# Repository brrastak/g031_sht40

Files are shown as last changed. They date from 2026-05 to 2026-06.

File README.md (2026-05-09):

# Temperature and humidity measuring device

Consists of:

- [SHT40 Temperature & Humidity Sensor](https://www.adafruit.com/product/4885);
- [1.02inch E-Ink display module](https://www.waveshare.com/1.02inch-e-paper-module.htm);
- [AEM10491 solar energy harvesting module](https://www.tindie.com/products/jaspersikken/solar-harvesting-into-supercapacitors/);
- two supercaps to store the energy;

all controlled by a rust-powered STM32G031 micro!

## Images

### Breadboard edition

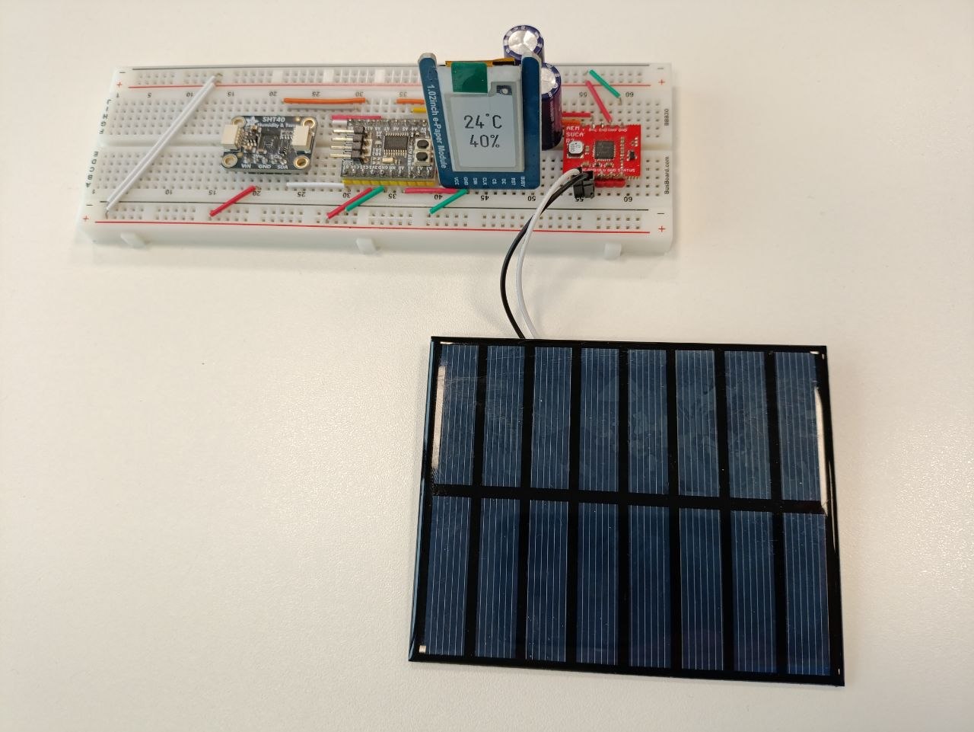
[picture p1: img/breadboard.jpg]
Breadboard


## Solar harvester

### Voltage thresholds

Enable threshold: 3.92V

Disable threshold: 3.60V

Unfortunately, the system doesn't work when supplied by 2.5V.

[AEM10491 datasheet](https://www.mouser.sk/datasheet/3/3770/1/DS_AEM10941.pdf)

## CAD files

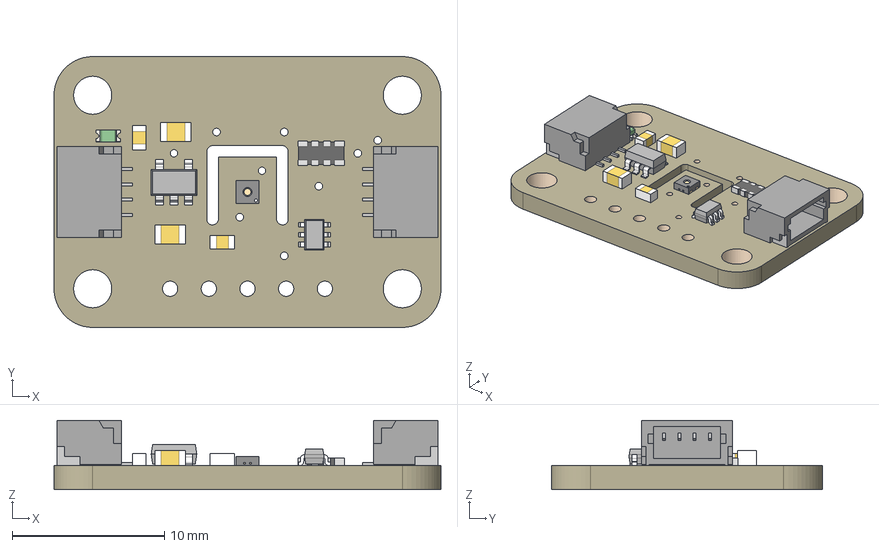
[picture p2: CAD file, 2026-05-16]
hardware/3d-models/SHT40.step
25.4 x 17.8 x 4.53 mm
Board
10uF x 2
AP2112K-3.3
10K x 2
10K_1
BSS138
STEMMA_I2C_QT x 2
GREEN
SHT4X_

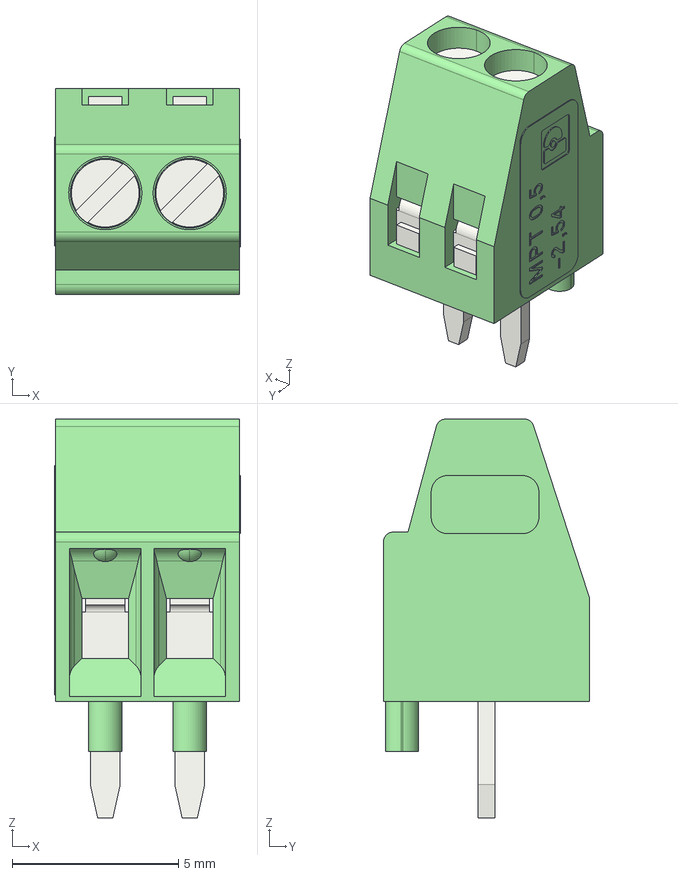
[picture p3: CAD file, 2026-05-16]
hardware/3d-models/1725656.stp
5.60 x 6.20 x 12.0 mm

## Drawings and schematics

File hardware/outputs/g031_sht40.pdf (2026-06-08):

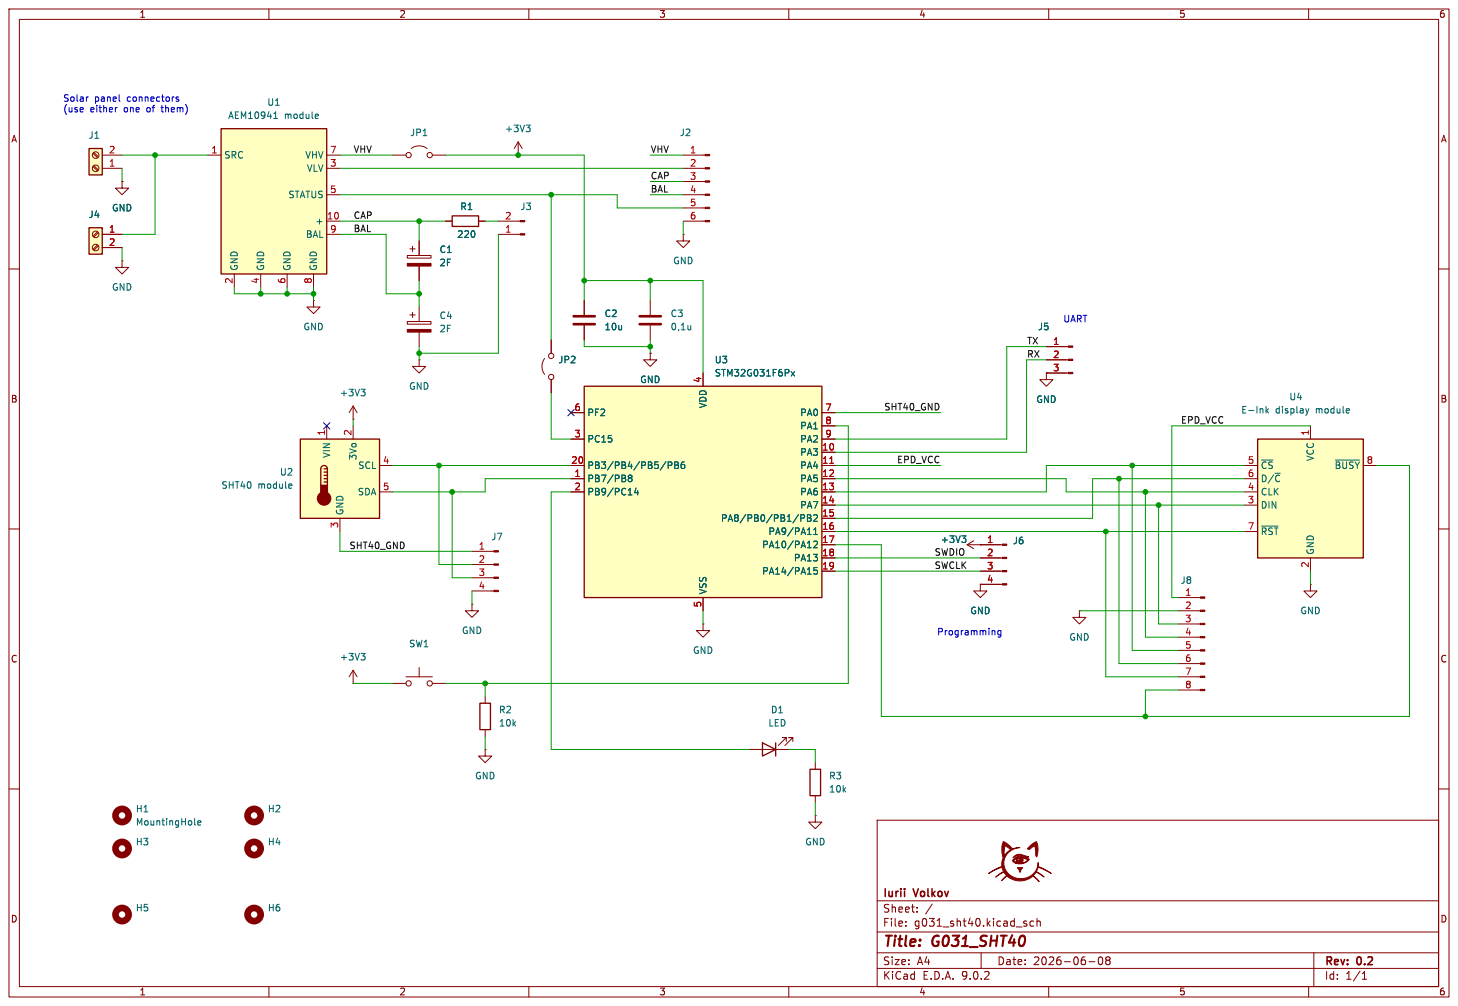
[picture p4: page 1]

(use either one of them) GND J4
10u GND GND

2 ~{BUSY}8 U4 E-Ink display module

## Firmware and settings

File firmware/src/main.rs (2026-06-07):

#![deny(unsafe_code)]
#![no_main]
#![no_std]

use defmt;
// Global logger
use defmt_rtt as _;
use hal::rtc::{self, Rtc};
use panic_halt as _;
use stm32g0xx_hal as hal;

use g031_sht40::bsp::{Board, Display, Led, Sensor};
use g031_sht40::data::{Data, UpdateStatus};

#[rtic::app(device = hal::pac, peripherals = true, dispatchers = [EXTI4_15])]
mod app {

    use super::*;

    #[shared]
    struct Shared {}

    #[local]
    struct Local {
        display: Display,
        sensor: Sensor,
        prev_data: Option<Data>,
        rtc: Rtc,
        led: Led,
    }

    #[init]
    fn init(cx: init::Context) -> (Shared, Local) {
        let board = Board::new(cx.device, cx.core);
        defmt::info!("Initialization finished!");

        let display = board.display;
        let sensor = board.sensor;
        let rtc = board.rtc;
        let led = board.led;

        let prev_data: Option<Data> = None;

        system_task::spawn().ok();

        (
            Shared {},
            Local {
                display,
                sensor,
                prev_data,
                rtc,
                led,
            },
        )
    }

    #[task(local = [display, sensor, prev_data], priority = 1)]
    async fn system_task(cx: system_task::Context) {
        let system_task::LocalResources {
            display,
            sensor,
            prev_data,
            ..
        } = cx.local;

        let data = sensor.read();
        if data.is_some() {
            let data = data.as_ref().unwrap();
            defmt::info!(
                "Temperature: {}°C Humidity: {}%",
                data.temperature,
                data.humidity
            );
        } else {
            defmt::warn!("Failed to read data from the sensor!");
        }

        let update_status = Data::check_update(data.as_ref(), prev_data.as_ref());

        display.partial_update(data.as_ref().unwrap_or(&Data::default()), update_status);

        *prev_data = data;
    }

    #[task(binds = RTC_TAMP, local = [rtc], priority = 2)]
    fn wake_up(cx: wake_up::Context) {
        let wake_up::LocalResources { rtc, .. } = cx.local;

        rtc.unpend(rtc::Event::AlarmA);

        let time = rtc.get_time();
        defmt::info!(
            "Wake up! Time: {}:{}:{}",
            time.hours,
            time.minutes,
            time.seconds
        );

        // let update_period_minutes = 1;
        let update_period_minutes = 5;
        if time.minutes % update_period_minutes == 0 {
            system_task::spawn().ok();
        }
    }

    /// Turns on the LED for a short time when the button is pressed
    /// to indicate that the device is powered
    #[task(binds = EXTI0_1, local = [led], priority = 2)]
    fn is_alive(cx: is_alive::Context) {
        let is_alive::LocalResources { led, .. } = cx.local;

        led.blink();

        led.exti_unpend();
    }

    #[idle]
    fn idle(_: idle::Context) -> ! {
        loop {
            cortex_m::asm::wfi();
        }
    }
}

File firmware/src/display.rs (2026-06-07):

//! EPD display related stuff

use embedded_graphics::prelude::*;
use epd_waveshare::{
    epd1in02::{self, Epd1in02},
    graphics::VarDisplay,
    prelude::*,
};
use hal::{
    gpio::{Input, Output, PullDown, PushPull, gpioa, gpioa::PA},
    prelude::*,
    rcc,
};
use stm32g0xx_hal as hal;
use u8g2_fonts::{FontRenderer, fonts, types::*};

use crate::bsp::{Epd, EpdDelay, EpdSpiDev};
use crate::data::{Data, UpdateStatus};
use crate::deactivate::{ActivatedEpdPins, DeactivatedEpdPins};

// type Frame = epd_waveshare::graphics::Display<80, 128, false, 1280, Color>;
type PartialFrame<'a> = VarDisplay<'a, Color>;
type Font = fonts::u8g2_font_logisoso24_tf;

const FONT: FontRenderer = FontRenderer::new::<Font>();
const TEXT_HEIGHT: u32 = FONT
    .get_font_bounding_box(VerticalPosition::Baseline)
    .size
    .height;
const TEXT_WIDTH: u32 = epd1in02::WIDTH;
/// Size of the frame buffer for one line of text
const FRAME_SIZE: usize = TEXT_HEIGHT as usize * TEXT_WIDTH as usize / 8;
/// Temperature text line Y coordinate
const TEMPERATURE_LINE_Y: u32 = epd1in02::HEIGHT / 2;
/// Humidity text line Y coordinate
const HUMIDITY_LINE_Y: u32 = epd1in02::HEIGHT / 2 - TEXT_HEIGHT;
/// Y coordinate for error message when data update fails
const ERROR_LINE_Y: u32 = epd1in02::HEIGHT / 2 - TEXT_HEIGHT / 2;
/// Y coordinate to update both lines
const BOTH_LINES_Y: u32 = HUMIDITY_LINE_Y;
/// Number of updates after which the screen will be fully cleared to prevent ghosting effect
const CLEAR_NUMBER_OF_UPDATES: u32 = 100;

pub enum RenderTarget {
    Temperature,
    Humidity,
    Error,
}

/// Display related HW
pub struct Display {
    epd: Epd,
    en_epd: gpioa::PA<Output<PushPull>>,
    spi_dev: EpdSpiDev,
    epd_delay: EpdDelay,
    /// For DeactivatedEpdPins
    pub rcc: rcc::Rcc,
    temperature_frame_buf: [u8; FRAME_SIZE],
    humidity_frame_buf: [u8; FRAME_SIZE],
    update_counter: u32,
}

impl Display {
    /// Create new Display instance and initialize EPD
    /// Arguments:
    /// - `spi_dev`: SPI device for EPD communication
    /// - `epd_busy`: EPD busy pin
    /// - `epd_dc`: EPD data/command pin
    /// - `epd_reset`: EPD reset pin
    /// - `epd_delay`: Delay provider
    /// - `en_epd`: GPIO pin to enable/disable EPD power
    /// - `rcc`: Reset and clock control for pin reconfiguration when deactivating EPD pins
    pub fn new(
        mut spi_dev: EpdSpiDev,
        epd_busy: PA<Input<PullDown>>,
        epd_dc: PA<Output<PushPull>>,
        epd_reset: PA<Output<PushPull>>,
        mut epd_delay: EpdDelay,
        mut en_epd: PA<Output<PushPull>>,
        mut rcc: rcc::Rcc,
    ) -> Self {
        en_epd.set_high().ok();

        let mut epd = Epd1in02::new(
            &mut spi_dev,
            epd_busy,
            epd_dc,
            epd_reset,
            &mut epd_delay,
            None,
        )
        .expect("EPD init error");
        epd.sleep(&mut spi_dev, &mut epd_delay).expect("EPD error");
        en_epd.set_low().ok();
        // Without that power consumption is ~50mA
        let _ = DeactivatedEpdPins::steal_epd_pins(&mut rcc);

        let background_color = epd.background_color().get_byte_value();

        Display {
            epd,
            en_epd,
            spi_dev,
            epd_delay,
            rcc,
            temperature_frame_buf: [background_color; FRAME_SIZE],
            humidity_frame_buf: [background_color; FRAME_SIZE],
            update_counter: 0,
        }
    }

    pub fn partial_update(&mut self, data: &Data, update_status: UpdateStatus) {
        if update_status == UpdateStatus::NoUpdate {
            defmt::info!("No update needed");
            return;
        }

        let background_color = self.epd.background_color().get_byte_value();
        let mut temperature_frame_buf = self.temperature_frame_buf;
        let mut humidity_frame_buf = self.humidity_frame_buf;

        // Activate EPD
        let activated_pins = self.activate_pins();
        self.en_epd.set_high().ok();
        self.epd
            .wake_up(&mut self.spi_dev, &mut self.epd_delay)
            .expect("EPD error");

        // Proceed full refresh
        self.update_counter += 1;
        if self.update_counter >= CLEAR_NUMBER_OF_UPDATES
            || update_status == UpdateStatus::UpdateBothFull
            || update_status == UpdateStatus::UpdateError
        {
            defmt::info!("Full screen refresh");
            self.epd
                .clear_frame(&mut self.spi_dev, &mut self.epd_delay)
                .expect("EPD error");
            self.update_counter = 0;
        }

        let mut render_and_update = |prev_frame_buf: &mut [u8; FRAME_SIZE],
                                     target: RenderTarget| {
            let mut new_frame_buf = [background_color; FRAME_SIZE];
            let new_frame = self.render_partial_frame(data, &mut new_frame_buf, &target);
            let y = match target {
                RenderTarget::Temperature => TEMPERATURE_LINE_Y,
                RenderTarget::Humidity => HUMIDITY_LINE_Y,
                RenderTarget::Error => ERROR_LINE_Y,
            };
            self.update_partial_frame(prev_frame_buf, new_frame, y);
            // Save buffer for the next update
            match target {
                RenderTarget::Temperature => {
                    self.temperature_frame_buf = new_frame_buf;
                }
                RenderTarget::Humidity => {
                    self.humidity_frame_buf = new_frame_buf;
                }
                RenderTarget::Error => (),
            }
        };
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

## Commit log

2026-02-05 Switch EPD off and deactivate pins to decrease current consumption
2026-02-19 Add low-power mode with RTC wakeup
2026-02-19 Replace monotonic to timer delay
    [main.rs]
2026-05-06 Refactor data processing for SHT4x sensor measurements
2026-05-06 Implement Sensor and Display functions
2026-05-07 Fix: deactivate EPD pins in init function
    [bsp.rs]
2026-05-10 Connect button to another pin (to avoid SWDIO conflict)
    [bsp.rs]
2026-05-16 Add PCB design files
    [1725656.stp, SHT40.step, g031_sht40.kicad_pcb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]
2026-05-17 Add Status pin connection
    [g031_sht40.kicad_pcb, g031_sht40.kicad_sch]
2026-05-17 Add schematic outputs
    [g031_sht40-B_Cu.gbl, g031_sht40-B_Mask.gbs, g031_sht40-B_Paste.gbp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]
2026-05-30 Add partial temperature update
2026-06-03 Implement partial update for both temperature and humidity
    [current_consumption.ods]
2026-06-07 Switch to panic-halt to decrease firmware size
2026-06-07 Fix old frame saving
    [display.rs]
2026-06-07 Change pin assignments according to PCB
2026-06-08 Fix pin assignments for EPD control
    [g031_sht40-B_Cu.gbl, g031_sht40-B_Mask.gbs, g031_sht40-B_Paste.gbp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]
